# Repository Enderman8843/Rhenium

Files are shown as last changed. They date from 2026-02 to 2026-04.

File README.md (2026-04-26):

# Rhenium 
It is a Keyboard that is powered by RP2040 microprocessor that uses a USB-C, this keyboard is using akko v3 pro black switches also this has a layout of a slight variation of ANSI-104 

### Demo : https://drive.google.com/file/d/1mEruNO0NkJvDSLDQcf2VO9Js_aKwS2UY/view?usp=sharing
### Demo : https://drive.google.com/file/d/1Fq-R3P4Wu6ONQhNlfD0M-4PFkLKanZj8/view
# Photos


# KMK FIRMWARE 
*ALWAYS USE THIS
1. Install CircuitPY
2. Copy these files: -https://github.com/Enderman8843/Rhenium/tree/f9bf0482101a7b040eca7897d7e98482e09b73b1/firmware/KMK%20FIRMWARE

# QMK FIRMWARE 
*Bit Glitchy 
1. Put this UF2 in rpi
https://github.com/Enderman8843/Rhenium/tree/909fbee6c6720d5a931a36db898d5d94f6ce02c9/firmware/UF2FILES/QMK

## Why Rhenium?
Personally I had never used a mechanical keyboard in my life and only relied on cheap membrane keyboard or use my laptop's keyboard , But when I heard about Blueprint I decided to change it all at once and build myself a Mechanical keyboard , And also decided that I need to have everything custom nothing extrenal thus I embeded the microprocessor into the pcb making it better!

Rhenium was named after the inspiration taken from the chromium browser!

## How To Use ?
To use this computer appartus I would suggest using your biological input device so called digits i.e. fingers ,Begin by selecting finger of your choice then elevate your finger about 0.3-0.4 cm above the desired key then place it in on that particular key then gently apply 0.30N of magnitude of force this would lead your visual display unit to render the desired character represented by the key , Simple as that

Before that make sure the assemeble the keyboard and connect it via the usb-c , and to flash the firmware use the bootsel btn and read the above for both KMK and QMK
## Case Render

| Top & Side View | Rear view |
|---|---|
|  |  |

| Full Assembly View |
|-------------------|
|  |

---

## PCB Layout and Render

| PCB  | Schematics /Wiring |
|---|---|
|  | |
| 3D view |
|-------------------|
|||

## JLCPCB ORDER 


## Shipment Option 


See I did not find gdsr option so I chose UPS world wide express shipment

## BOM
| Item | Description | Quantity | Unit Price ($) | Total Price ($) | URL |
|---|---|---|---|---|-----|
| PCB | JLCPCB | 1 | 113.66 | 113.66 | https://jlcpcb.com |
| Pinecil V2 | Solder Iron | 1 | OWNED | 0.00 | OWNED |
| Diodes | Diodes | 75 | 0.01 | 1 | Owned |
| Case | Print Legion Shipment | 1 | 6.00 | 6.00 | https://hackclub.com |
| Akko Switches | Switch Set (45) | 2 | 14.00 | 28.00 | https://stackskb.com/store/akko-v3-cream-black-pro-switch-pack-of-45/ |
| Keycaps | MDA Profile Keycaps | 1 | 16.69 | 16.69 | https://stackskb.com/store/stackspbt-lavender-mda-profile-keycaps-131-key/ |
| OLED Display | 0.91" OLED Display | 1 | 2.23 | 2.23 | https://robu.in/product/blue-oled-display-module/ |
| Vertical Rotary Encoder | Rotary Encoder | 1 | 2.00 | 2.00 | https://www.amazon.in/dp/B0888RWNM1 |
| Rotary Cap | Knob Cap | 1 | 0.40 | 0.40 | https://robu.in/product/potentiometer-knob-rotary-switch-cap-black-color-pack-of-5-pcs/ |
| M2 Screw + Hex + Washer | Misc Hardware | 6 | 0.80 | 0.80 | https://onlyscrews.in/products/m2-nut-ss-304 |
| Soldering Essentials | Solder+Flux+TipCleaner | 1 | 4.54 | 4.54 | https://robocraze.com/products/7cmx5-5cm-soldering-cleaning-sponge-for-soldering-irons-work-stands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 , https://robu.in/product/solder-wire-0-8mm50g/ , https://robu.in/product/noel-flux-soldering-paste-10g/ |
| **TOTAL** |  |  |  | **175 $** |  |

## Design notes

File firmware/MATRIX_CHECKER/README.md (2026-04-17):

This files helped me quite a lot to find the wrong diodes in my keyboard

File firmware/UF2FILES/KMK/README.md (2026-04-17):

It is the default circuitpy uf2 , You have to put the files from KMK firware in circuitpy disk then it will work

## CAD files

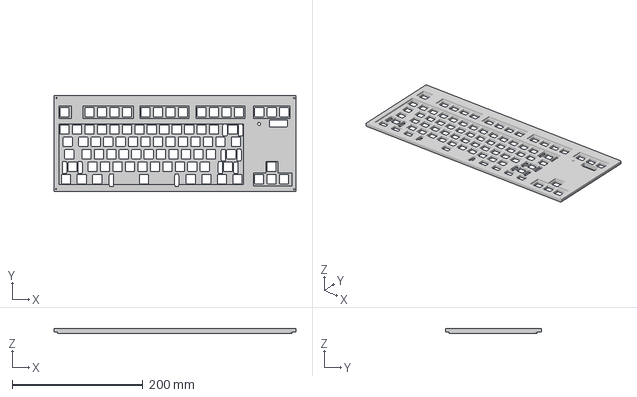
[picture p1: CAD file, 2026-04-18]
CAD/3d_Printable Files/LEFT_KEEBPLATE.3mf
370.0 x 146.1 x 7.20 mm

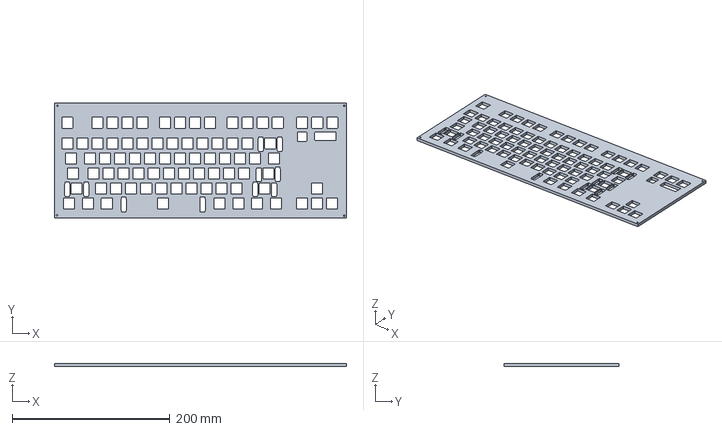
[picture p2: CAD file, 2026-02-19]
CAD/Keyboard_Plate.step
370.0 x 146.1 x 4.00 mm

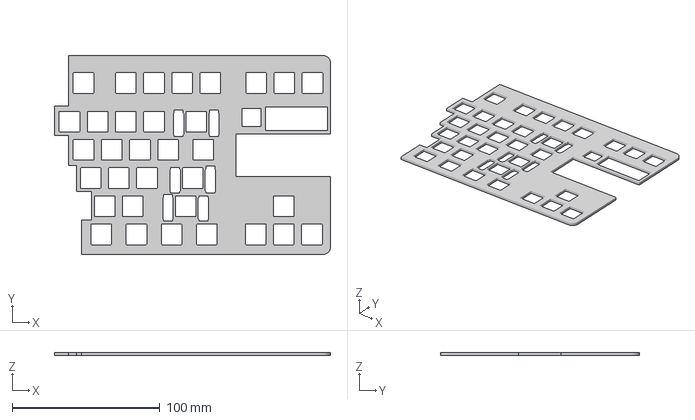
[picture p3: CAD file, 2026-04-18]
CAD/3d_Printable Files/RIGHT_KEEBPLATE.3mf
186.6 x 134.4 x 2.20 mm

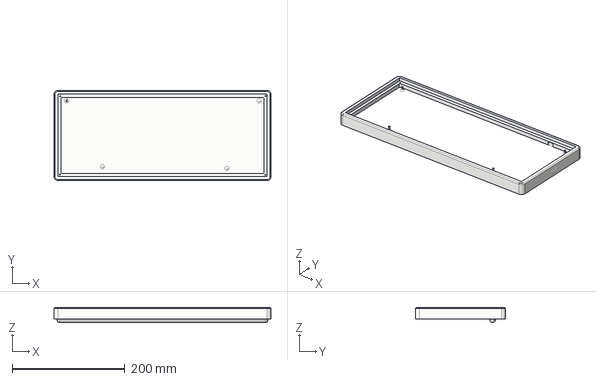
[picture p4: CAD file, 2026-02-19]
CAD/Keyboard_Body.step
384.6 x 159.5 x 26.9 mm

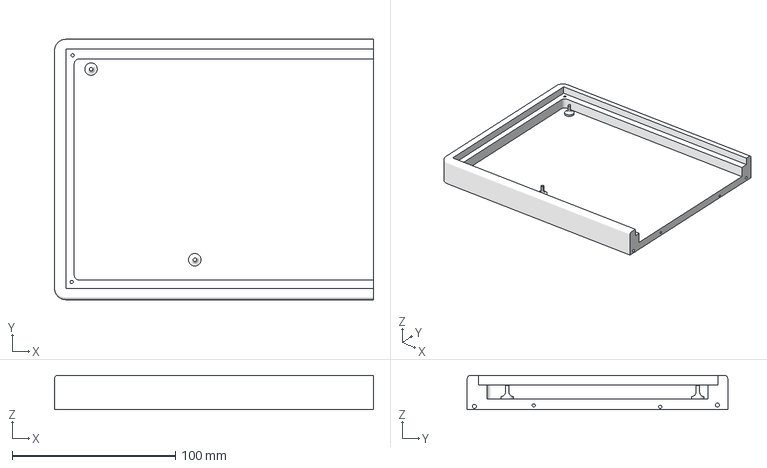
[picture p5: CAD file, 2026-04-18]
CAD/3d_Printable Files/BODY_RIGHT.3mf
195.3 x 159.5 x 21.0 mm

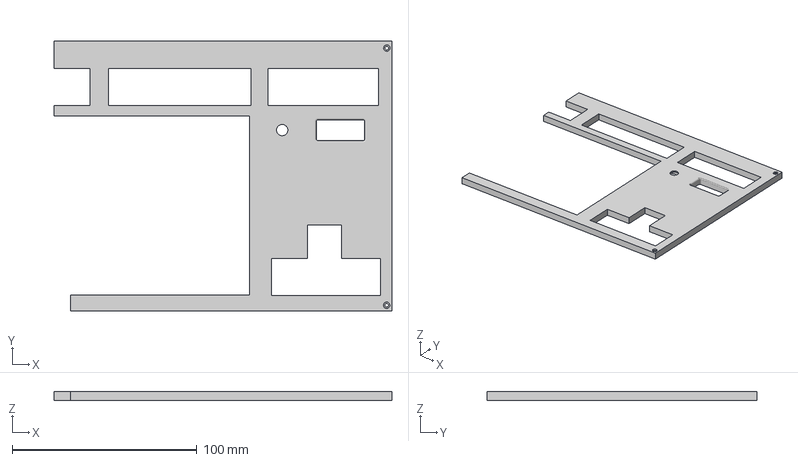
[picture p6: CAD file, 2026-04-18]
CAD/3d_Printable Files/TOP_LEFT.3mf
183.2 x 146.1 x 5.00 mm

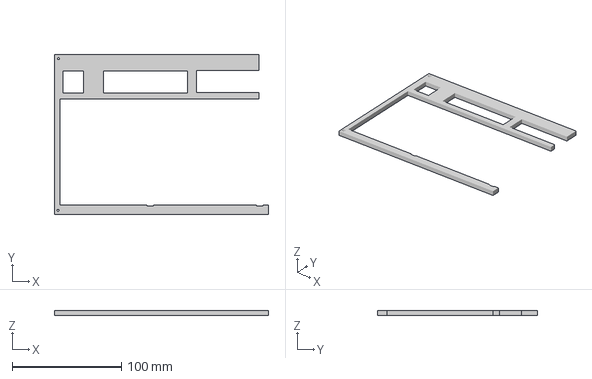
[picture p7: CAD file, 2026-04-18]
CAD/3d_Printable Files/TOP_RIGHT.3mf
195.7 x 146.1 x 4.90 mm

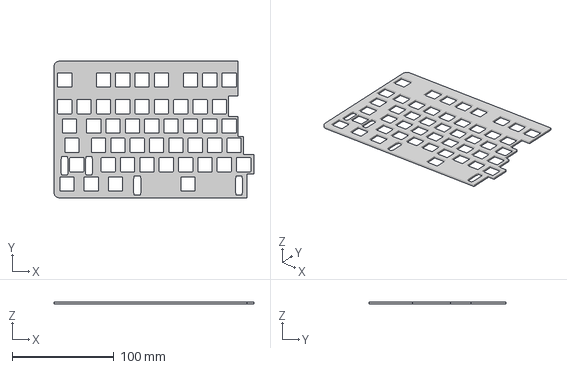
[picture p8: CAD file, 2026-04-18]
CAD/3d_Printable Files/RIGHTSIDE.3mf
196.9 x 134.4 x 2.20 mm

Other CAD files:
CAD/3d_Printable Files/LEFTSIDE.3mf

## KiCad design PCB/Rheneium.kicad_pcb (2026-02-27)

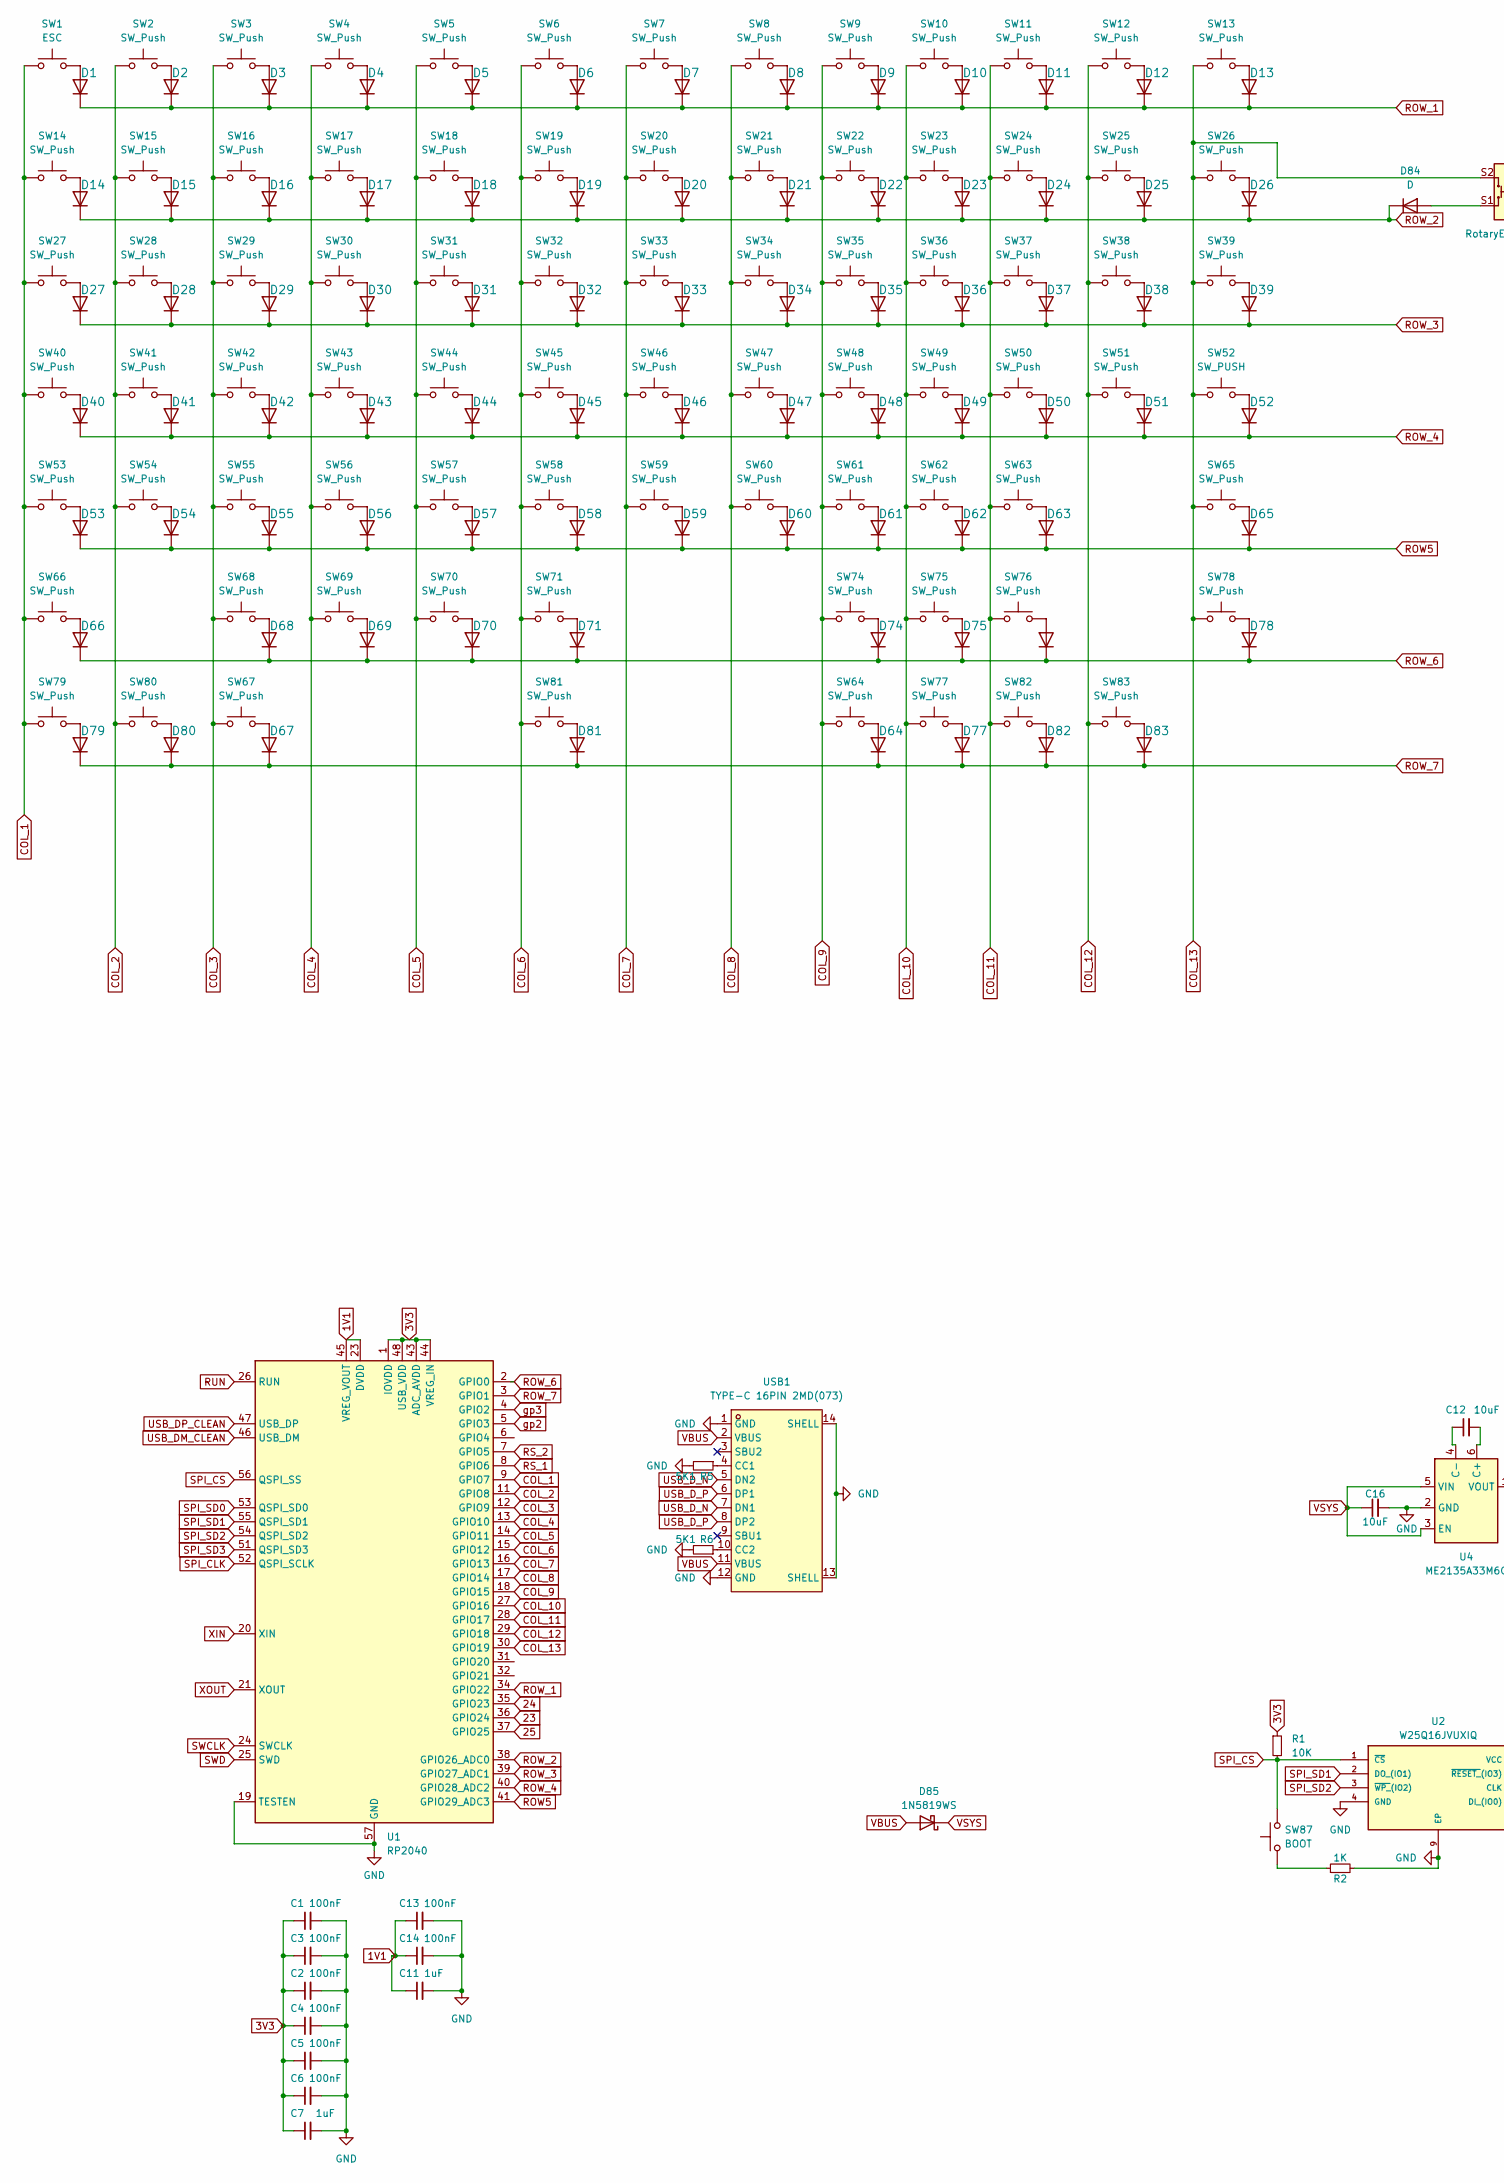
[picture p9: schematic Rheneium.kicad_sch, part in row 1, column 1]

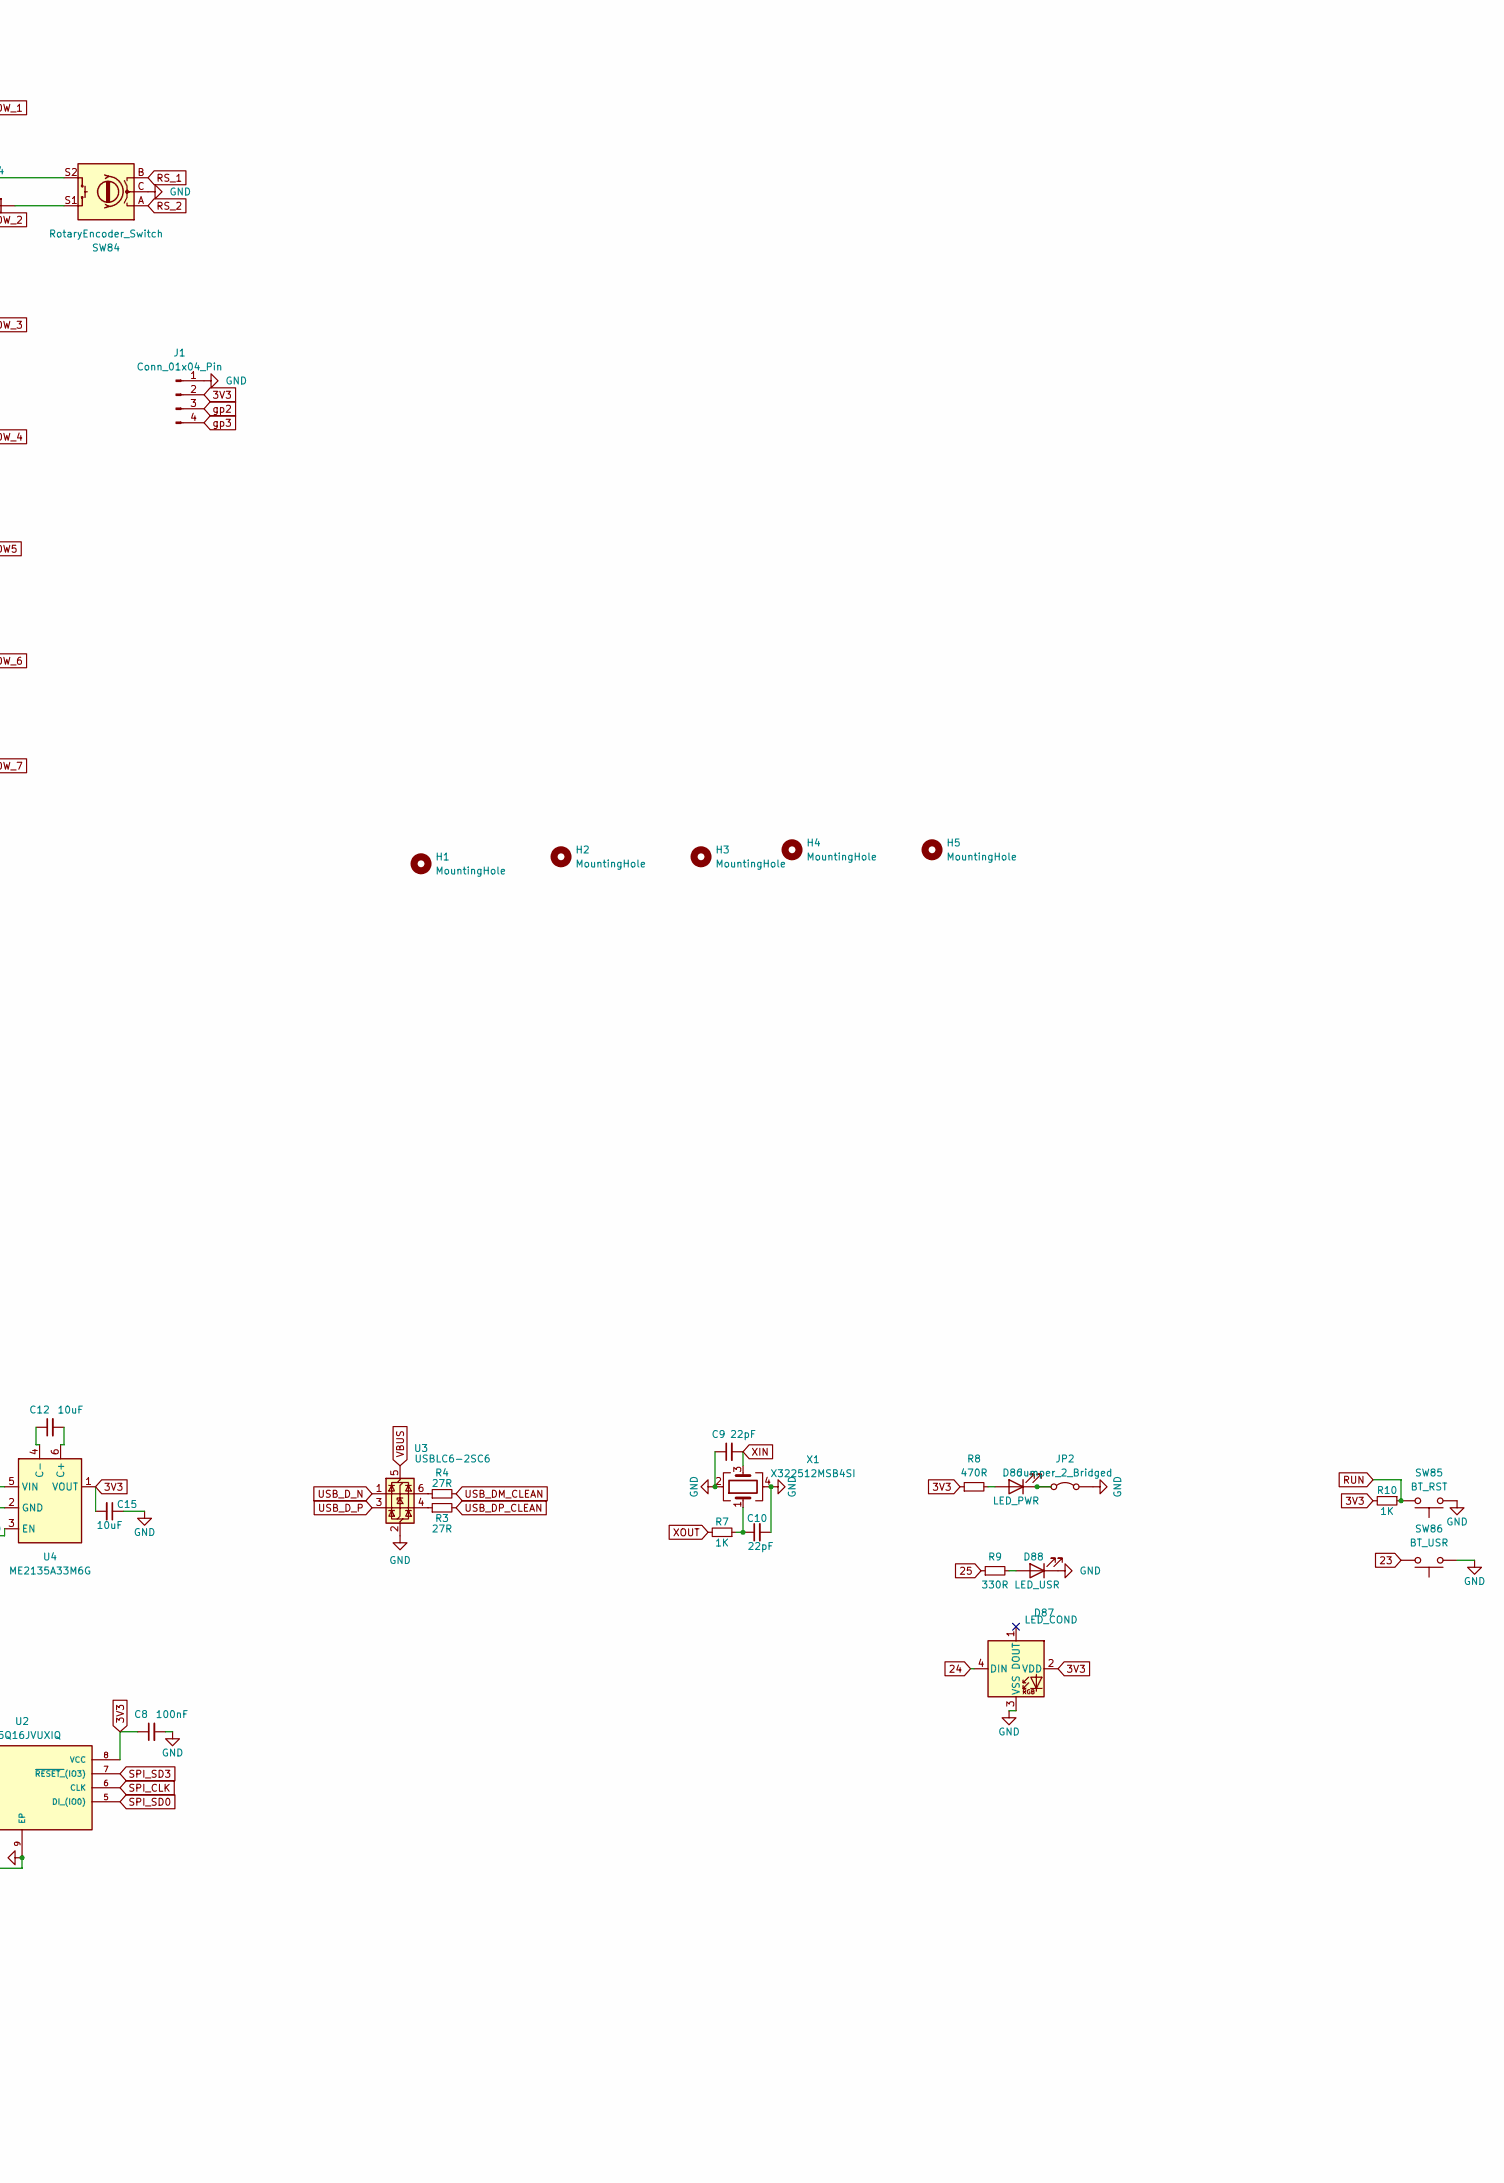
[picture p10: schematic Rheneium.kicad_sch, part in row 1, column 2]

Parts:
C1, C2, C3, C4, C5, C6, C8, C13, C14: 100nF; C_0402_1005Metric
C7, C11: 1uF; C_0402_1005Metric
C9, C10: 22pF; C_0402_1005Metric
C12: 10uF; C_0805_2012Metric
C15, C16: 10uF; C_0402_1005Metric
D1, D2, D3, D4, D5, D6, D7, D8, D9, D10, D11, D12, D13, D14, D15, D16, D17, D18, D19, D20, D21, D22, D23, D24, D25, D26, D27, D28, D29, D30, D31, D32, D33, D34, D35, D36, D37, D38, D39, D40, D41, D42, D43, D44, D45, D46, D47, D48, D49, D50, D51, D52, D53, D54, D55, D56, D57, D58, D59, D60, D61, D62, D63, D64, D65, D66, D67, D68, D69, D70, D71, D74, D75, D76, D77, D78, D79, D80, D81, D82, D83, D84: D; D_0805_2012Metric_Pad1.15x1.40mm_HandSolder
D85: 1N5819WS; D_SOD-323
D86: LED_PWR; LED_0603_1608Metric
D87: LED_COND; LED_SK6812MINI_PLCC4_3.5x3.5mm_P1.75mm
D88: LED_USR; LED_0603_1608Metric
H1, H2, H3, H4, H5: MountingHole; MountingHole_2.2mm_M2
J1: Conn_01x04_Pin; SSD1306-0.91-OLED-4pin-128x32
JP2: Jumper_2_Bridged; SolderJumper-2_P1.3mm_Bridged2Bar_RoundedPad1.0x1.5mm
R1: 10K; R_0402_1005Metric
R2, R7, R10: 1K; R_0402_1005Metric
R3, R4: 27R; R_0402_1005Metric
R5, R6: 5K1; R_0402_1005Metric
R8: 470R; R_0402_1005Metric
R9: 330R; R_0402_1005Metric
SW1: ESC; SW_Cherry_MX_1.00u_PCB
SW2, SW3, SW4, SW5, SW6, SW7, SW8, SW9, SW10, SW11, SW12, SW13, SW14, SW15, SW16, SW17, SW18, SW19, SW20, SW21, SW22, SW23, SW24, SW25, SW28, SW29, SW30, SW31, SW32, SW33, SW34, SW35, SW36, SW37, SW38, SW41, SW42, SW43, SW44, SW45, SW46, SW47, SW48, SW49, SW50, SW51, SW54, SW55, SW56, SW57, SW58, SW59, SW60, SW61, SW62, SW63, SW66, SW68, SW69, SW70, SW71, SW74, SW75, SW76, SW78: SW_Push; SW_Cherry_MX_1.00u_PCB
SW26: SW_Push; SW_Cherry_MX_2.00u_PCB
SW27, SW39: SW_Push; SW_Cherry_MX_1.50u_PCB
SW40: SW_Push; SW_Cherry_MX_1.75u_PCB
SW52: SW_PUSH; SW_Cherry_MX_2.25u_PCB
SW53: SW_Push; SW_Cherry_MX_2.25u_PCB
SW64, SW67, SW77, SW79, SW80, SW82, SW83: SW_Push; SW_Cherry_MX_1.25u_PCB
SW65: SW_Push; SW_Cherry_MX_2.75u_PCB
SW81: SW_Push; SW_Cherry_MX_6.25u_PCB
SW84: RotaryEncoder_Switch; RotaryEncoder_Alps_EC11E-Switch_Vertical_H20mm
SW85: BT_RST; SW_Push_1P1T_NO_CK_KMR2
SW86: BT_USR; SW_Push_1P1T_NO_CK_KMR2
SW87: BOOT; SW_Push_1P1T_NO_CK_KMR2
U1: RP2040; QFN-56-1EP_7x7mm_P0.4mm_EP3.2x3.2mm
U2: W25Q16JVUXIQ; Winbond_USON-8-1EP_3x2mm_P0.5mm_EP0.2x1.6mm; MANUFACTURER_PART_NUMBER W25Q16JVUXIQ; LCSC C2843335
U3: USBLC6-2SC6; SOT-23-6
U4: ME2135A33M6G; SOT-23-6; LCSC C610271
USB1: TYPE-C 16PIN 2MD(073); USB-C-SMD_TYPE-C-6PIN-2MD-073; LCSC Part C2765186
X1: X322512MSB4SI; Crystal_SMD_3225-4Pin_3.2x2.5mm; LCSC C9002

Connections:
1V1: C11.1, C13.1, C14.1, U1.23 (DVDD), U1.45 (VREG_VOUT), U1.50 (DVDD)
3V3: C1.1, C2.1, C3.1, C4.1, C5.1, C6.1, C7.1, C8.1, C15.2, D87.2 (VDD), J1.2, R1.1, R8.1, R10.2, U1.1 (IOVDD), U1.10 (IOVDD), U1.22 (IOVDD), U1.33 (IOVDD), U1.42 (IOVDD), U1.43 (ADC_AVDD), U1.44 (VREG_IN), U1.48 (USB_VDD), U1.49 (IOVDD), U2.8 (VCC), U4.1 (VOUT)
23: SW86.2, U1.36 (GPIO24)
24: D87.4 (DIN), U1.35 (GPIO23)
25: R9.1, U1.37 (GPIO25)
COL_1: SW1.1, SW14.1, SW27.1, SW40.1, SW53.1, SW66.1, SW79.1, U1.9 (GPIO7)
COL_2: SW2.1, SW15.1, SW28.1, SW41.1, SW54.1, SW80.1, U1.11 (GPIO8)
COL_3: SW3.1, SW16.1, SW29.1, SW42.1, SW55.1, SW67.1, SW68.1, U1.12 (GPIO9)
COL_4: SW4.1, SW17.1, SW30.1, SW43.1, SW56.1, SW69.1, U1.13 (GPIO10)
COL_5: SW5.1, SW18.1, SW31.1, SW44.1, SW57.1, SW70.1, U1.14 (GPIO11)
COL_6: SW6.1, SW19.1, SW32.1, SW45.1, SW58.1, SW71.1, SW81.1, U1.15 (GPIO12)
COL_7: SW7.1, SW20.1, SW33.1, SW46.1, SW59.1, U1.16 (GPIO13)
COL_8: SW8.1, SW21.1, SW34.1, SW47.1, SW60.1, U1.17 (GPIO14)
COL_9: SW9.1, SW22.1, SW35.1, SW48.1, SW61.1, SW64.1, SW74.1, U1.18 (GPIO15)
COL_10: SW10.1, SW23.1, SW36.1, SW49.1, SW62.1, SW75.1, SW77.1, U1.27 (GPIO16)
COL_11: SW11.1, SW24.1, SW37.1, SW50.1, SW63.1, SW76.1, SW82.1, U1.28 (GPIO17)
COL_12: SW12.1, SW25.1, SW38.1, SW51.1, SW83.1, U1.29 (GPIO18)
COL_13: SW13.1, SW26.1, SW39.1, SW52.1, SW65.1, SW78.1, SW84.S2, U1.30 (GPIO19)
GND: C1.2, C2.2, C3.2, C4.2, C5.2, C6.2, C7.2, C8.2, C9.1, C10.2, C11.2, C13.2, C14.2, C15.1, C16.2, D87.3 (VSS), D88.1 (K), J1.1, JP2.2 (B), R2.2, R5.2, R6.2, SW84.C, SW85.1, SW86.1, U1.19 (TESTEN), U1.57 (GND), U2.4 (GND), U2.9 (EP), U3.2 (GND), U4.2 (GND), USB1.1 (GND), USB1.12 (GND), USB1.13 (SHELL), USB1.14 (SHELL), X1.2, X1.4
unnamed: C10.1, R7.1, X1.1
unnamed: D1.2 (A), SW1.2
unnamed: D2.2 (A), SW2.2
unnamed: D3.2 (A), SW3.2
unnamed: D4.2 (A), SW4.2
unnamed: D5.2 (A), SW5.2
unnamed: D6.2 (A), SW6.2
unnamed: D7.2 (A), SW7.2
unnamed: D8.2 (A), SW8.2
unnamed: D9.2 (A), SW9.2
unnamed: D10.2 (A), SW10.2
unnamed: D11.2 (A), SW11.2
unnamed: D12.2 (A), SW12.2
unnamed: D13.2 (A), SW13.2
unnamed: D14.2 (A), SW14.2
unnamed: D15.2 (A), SW15.2
unnamed: D16.2 (A), SW16.2
unnamed: D17.2 (A), SW17.2
unnamed: D18.2 (A), SW18.2
unnamed: D19.2 (A), SW19.2
unnamed: D20.2 (A), SW20.2
unnamed: D21.2 (A), SW21.2
unnamed: D22.2 (A), SW22.2
unnamed: D23.2 (A), SW23.2
unnamed: D24.2 (A), SW24.2
unnamed: D25.2 (A), SW25.2
unnamed: D26.2 (A), SW26.2
unnamed: D27.2 (A), SW27.2
unnamed: D28.2 (A), SW28.2
unnamed: D29.2 (A), SW29.2
unnamed: D30.2 (A), SW30.2
unnamed: D31.2 (A), SW31.2
unnamed: D32.2 (A), SW32.2
unnamed: D33.2 (A), SW33.2
unnamed: D34.2 (A), SW34.2
unnamed: D35.2 (A), SW35.2
unnamed: D36.2 (A), SW36.2
unnamed: D37.2 (A), SW37.2
unnamed: D38.2 (A), SW38.2
unnamed: D39.2 (A), SW39.2
unnamed: D40.2 (A), SW40.2
unnamed: D41.2 (A), SW41.2
unnamed: D42.2 (A), SW42.2
unnamed: D43.2 (A), SW43.2
unnamed: D44.2 (A), SW44.2
unnamed: D45.2 (A), SW45.2
unnamed: D46.2 (A), SW46.2
unnamed: D47.2 (A), SW47.2
unnamed: D48.2 (A), SW48.2
unnamed: D49.2 (A), SW49.2
unnamed: D50.2 (A), SW50.2
unnamed: D51.2 (A), SW51.2
unnamed: D52.2 (A), SW52.2
unnamed: D53.2 (A), SW53.2
unnamed: D54.2 (A), SW54.2
unnamed: D55.2 (A), SW55.2
unnamed: D56.2 (A), SW56.2
unnamed: D57.2 (A), SW57.2
unnamed: D58.2 (A), SW58.2
unnamed: D59.2 (A), SW59.2
unnamed: D60.2 (A), SW60.2
unnamed: D61.2 (A), SW61.2
unnamed: D62.2 (A), SW62.2
unnamed: D63.2 (A), SW63.2
unnamed: D64.2 (A), SW64.2
unnamed: D65.2 (A), SW65.2
unnamed: D66.2 (A), SW66.2
unnamed: D67.2 (A), SW67.2
unnamed: D68.2 (A), SW68.2
unnamed: D69.2 (A), SW69.2
unnamed: D70.2 (A), SW70.2
unnamed: D71.2 (A), SW71.2
unnamed: D74.2 (A), SW74.2
unnamed: D75.2 (A), SW75.2
unnamed: D76.2 (A), SW76.2
unnamed: D77.2 (A), SW77.2
unnamed: D78.2 (A), SW78.2
unnamed: D79.2 (A), SW79.2
unnamed: D80.2 (A), SW80.2
unnamed: D81.2 (A), SW81.2
unnamed: D82.2 (A), SW82.2
unnamed: D83.2 (A), SW83.2
unnamed: D84.2 (A), SW84.S1
unnamed: D86.2 (A), R8.2
unnamed: D86.1 (K), JP2.1 (A)
unnamed: D88.2 (A), R9.2
unnamed: R2.1, SW87.1
unnamed: R3.1, U3.4 (I/O2)
unnamed: R4.1, U3.6 (I/O1)
unnamed: C12.2, U4.6 (C+)
unnamed: C12.1, U4.4 (C-)
unnamed: R5.1, USB1.4 (CC1)
unnamed: R6.1, USB1.10 (CC2)
ROW5: D53.1 (K), D54.1 (K), D55.1 (K), D56.1 (K), D57.1 (K), D58.1 (K), D59.1 (K), D60.1 (K), D61.1 (K), D62.1 (K), D63.1 (K), D65.1 (K), U1.41 (GPIO29_ADC3)
ROW_1: D1.1 (K), D2.1 (K), D3.1 (K), D4.1 (K), D5.1 (K), D6.1 (K), D7.1 (K), D8.1 (K), D9.1 (K), D10.1 (K), D11.1 (K), D12.1 (K), D13.1 (K), U1.34 (GPIO22)
ROW_2: D14.1 (K), D15.1 (K), D16.1 (K), D17.1 (K), D18.1 (K), D19.1 (K), D20.1 (K), D21.1 (K), D22.1 (K), D23.1 (K), D24.1 (K), D25.1 (K), D26.1 (K), D84.1 (K), U1.38 (GPIO26_ADC0)
ROW_3: D27.1 (K), D28.1 (K), D29.1 (K), D30.1 (K), D31.1 (K), D32.1 (K), D33.1 (K), D34.1 (K), D35.1 (K), D36.1 (K), D37.1 (K), D38.1 (K), D39.1 (K), U1.39 (GPIO27_ADC1)
ROW_4: D40.1 (K), D41.1 (K), D42.1 (K), D43.1 (K), D44.1 (K), D45.1 (K), D46.1 (K), D47.1 (K), D48.1 (K), D49.1 (K), D50.1 (K), D51.1 (K), D52.1 (K), U1.40 (GPIO28_ADC2)
ROW_6: D66.1 (K), D68.1 (K), D69.1 (K), D70.1 (K), D71.1 (K), D74.1 (K), D75.1 (K), D76.1 (K), D78.1 (K), U1.2 (GPIO0)
ROW_7: D64.1 (K), D67.1 (K), D77.1 (K), D79.1 (K), D80.1 (K), D81.1 (K), D82.1 (K), D83.1 (K), U1.3 (GPIO1)
RS_1: SW84.B, U1.8 (GPIO6)
RS_2: SW84.A, U1.7 (GPIO5)
RUN: R10.1, SW85.2, U1.26 (RUN)
SPI_CLK: U1.52 (QSPI_SCLK), U2.6 (CLK)
SPI_CS: R1.2, SW87.2, U1.56 (QSPI_SS), U2.1 (~CS)
SPI_SD0: U1.53 (QSPI_SD0), U2.5 (DI_(IO0))
SPI_SD1: U1.55 (QSPI_SD1), U2.2 (DO_(IO1))
SPI_SD2: U1.54 (QSPI_SD2), U2.3 (~WP_(IO2))
SPI_SD3: U1.51 (QSPI_SD3), U2.7 (~RESET_(IO3))
SWCLK: U1.24 (SWCLK)
SWD: U1.25 (SWD)
USB_DM_CLEAN: R4.2, U1.46 (USB_DM)
USB_DP_CLEAN: R3.2, U1.47 (USB_DP)
USB_D_N: U3.1 (I/O1), USB1.5 (DN2), USB1.7 (DN1)
USB_D_P: U3.3 (I/O2), USB1.6 (DP1), USB1.8 (DP2)
VBUS: D85.2 (A), U3.5 (VBUS), USB1.2 (VBUS), USB1.11 (VBUS)
VSYS: C16.1, D85.1 (K), U4.3 (EN), U4.5 (VIN)
XIN: C9.2, U1.20 (XIN), X1.3
XOUT: R7.2, U1.21 (XOUT)
gp2: J1.3, U1.5 (GPIO3)
gp3: J1.4, U1.4 (GPIO2)

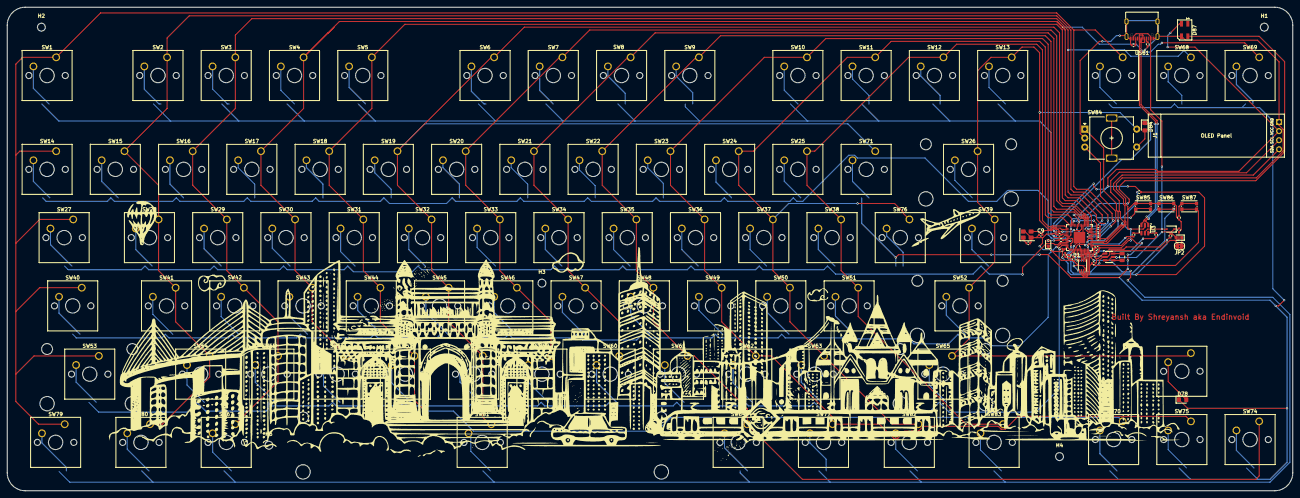
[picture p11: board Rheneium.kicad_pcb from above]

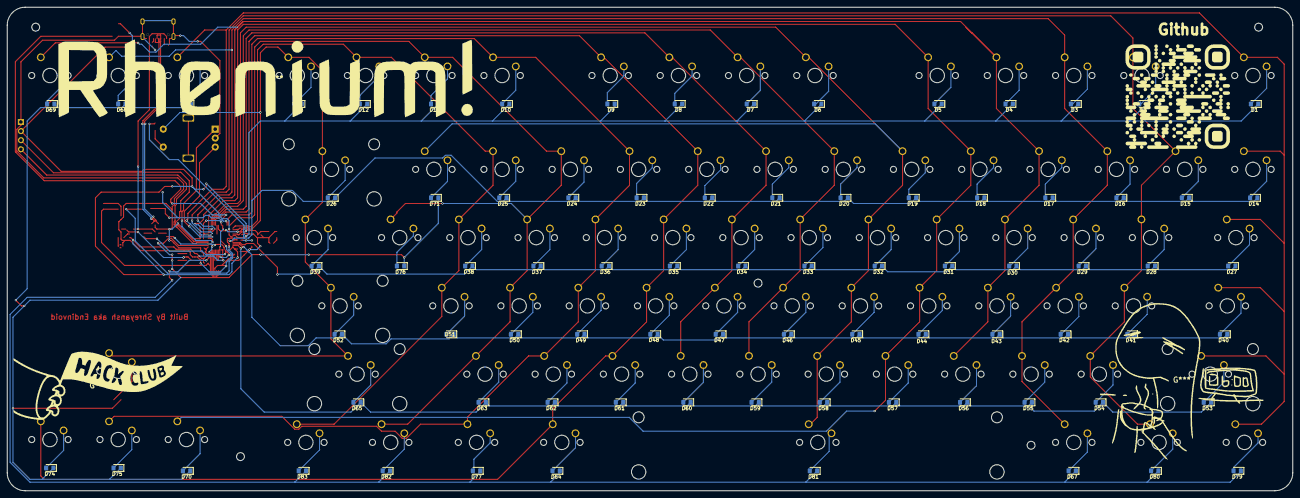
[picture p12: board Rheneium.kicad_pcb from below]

Board: 2 copper layers, 358.8 x 134.9 mm, 209 parts (80 on the bottom side), 137 nets.

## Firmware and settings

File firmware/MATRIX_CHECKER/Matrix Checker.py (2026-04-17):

from kmk.kmk_keyboard import KMKKeyboard
from kmk.keys import KC
from kmk.scanners import DiodeOrientation
import board
import time
import busio
import adafruit_ssd1306

keyboard = KMKKeyboard()

# ---------------- MATRIX ----------------
keyboard.row_pins = (
    board.GP16, board.GP17, board.GP18,
    board.GP19, board.GP20, board.GP21, board.GP22
)

keyboard.col_pins = (
    board.GP2, board.GP3, board.GP4, board.GP5,
    board.GP6, board.GP7, board.GP8,
    board.GP9, board.GP10, board.GP11,
    board.GP12, board.GP13, board.GP14
)

# ⚠️ If keys don't work, switch this
keyboard.diode_orientation = DiodeOrientation.COL2ROW
# keyboard.diode_orientation = DiodeOrientation.ROW2COL


# ---------------- OLED ----------------
i2c = busio.I2C(scl=board.GP27, sda=board.GP26)
oled = adafruit_ssd1306.SSD1306_I2C(128, 32, i2c, addr=0x3C)

# Fix orientation (very common issue)
oled.rotate(2)


# ---------------- BOOT ----------------
def boot_logo():
    oled.fill(0)
    oled.text("RHENIUM", 30, 8, 1)
    oled.text("READY", 40, 18, 1)
    oled.show()
    time.sleep(1.2)

boot_logo()


# ---------------- STATS ----------------
start_time = time.monotonic()
keypress_count = 0
last_key = ""
last_oled_update = 0


def get_wpm():
    elapsed = time.monotonic() - start_time
    if elapsed == 0:
        return 0
    return int((keypress_count / 5) / (elapsed / 60))


# ---------------- KEY HANDLING (FIXED) ----------------
keyboard._orig_process_key = keyboard.process_key

def process_key(key, is_pressed, int_coord):
    global keypress_count, last_key

    if is_pressed:
        keypress_count += 1
        last_key = str(key).replace("KC.", "")

    # IMPORTANT: pass back to KMK
    return keyboard._orig_process_key(key, is_pressed, int_coord)

keyboard.process_key = process_key


# ---------------- OLED RENDER (FAST) ----------------
def render_oled():
    oled.fill(0)

    # Key (top row)
    oled.text("K:" + last_key[:6], 0, 0, 1)

    # WPM (bottom row)
    oled.text("WPM:" + str(get_wpm()), 0, 16, 1)

    oled.show()


# ---------------- THROTTLED UPDATE ----------------
def after_matrix_scan(*args):
    global last_oled_update

    now = time.monotonic()

    # Update at ~5 FPS (no lag)
    if now - last_oled_update > 0.2:
        last_oled_update = now
        render_oled()

keyboard.after_matrix_scan = after_matrix_scan


# ---------------- KEYMAP ----------------
keyboard.keymap = [[
    KC.ESC, KC.F1, KC.F2, KC.F3, KC.F4, KC.F5, KC.F6, KC.F7, KC.F8, KC.F9, KC.F10, KC.F11, KC.F12,
    KC.GRV, KC.N1, KC.N2, KC.N3, KC.N4, KC.N5, KC.N6, KC.N7, KC.N8, KC.N9, KC.N0, KC.MINS, KC.BSPC,
    KC.TAB, KC.Q, KC.W, KC.E, KC.R, KC.T, KC.Y, KC.U, KC.I, KC.O, KC.P, KC.LBRC, KC.BSLS,
    KC.CAPS, KC.A, KC.S, KC.D, KC.F, KC.G, KC.H, KC.J, KC.K, KC.L, KC.SCLN, KC.QUOT, KC.ENTER,
    KC.LSHIFT, KC.Z, KC.X, KC.C, KC.V, KC.B, KC.N, KC.M, KC.COMM, KC.DOT, KC.SLSH, KC.NO, KC.RSHIFT,
    KC.PSCR, KC.NO, KC.NO, KC.PAUSE, KC.LEFT, KC.EQL, KC.NO, KC.NO, KC.RIGHT, KC.DOWN, KC.RBRC, KC.NO, KC.UP,
    KC.LCTRL, KC.LGUI, KC.LALT, KC.NO, KC.NO, KC.SPACE, KC.NO, KC.NO, KC.RALT, KC.NO, KC.APP, KC.RCTRL, KC.NO
]]


# ---------------- START ----------------
if __name__ == '__main__':
    keyboard.go()

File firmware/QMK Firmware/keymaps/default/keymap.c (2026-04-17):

#include QMK_KEYBOARD_H

#define ENCODER_MAP_ENABLE

bool encoder_mode = false;
uint8_t volume_level = 50;
uint8_t brightness_level = 50;

const uint16_t PROGMEM keymaps[][MATRIX_ROWS][MATRIX_COLS] = {
[0] = LAYOUT(
KC_ESC, KC_F1, KC_F2, KC_F3, KC_F4, KC_F5, KC_F6, KC_F7, KC_F8, KC_F9, KC_F10, KC_F11, KC_F12,
KC_GRV, KC_1, KC_2, KC_3, KC_4, KC_5, KC_6, KC_7, KC_8, KC_9, KC_0, KC_MINS, KC_BSPC,
KC_TAB, KC_Q, KC_W, KC_E, KC_R, KC_T, KC_Y, KC_U, KC_I, KC_O, KC_P, KC_LBRC, KC_BSLS,
KC_CAPS, KC_A, KC_S, KC_D, KC_F, KC_G, KC_H, KC_J, KC_K, KC_L, KC_SCLN, KC_QUOT, KC_ENT,
KC_LSFT, KC_Z, KC_X, KC_C, KC_V, KC_B, KC_N, KC_M, KC_COMM, KC_DOT, KC_SLSH, KC_NO, KC_RSFT,
KC_PSCR, KC_NO, KC_NO, KC_PAUS, KC_LEFT, KC_EQL, KC_NO, KC_NO, KC_RGHT, KC_DOWN, KC_RBRC, KC_NO, KC_UP,
KC_LCTL, KC_LGUI, KC_LALT, KC_NO, KC_NO, KC_SPC, KC_NO, KC_NO, KC_RALT, KC_NO, KC_APP, KC_RCTL, KC_NO
)
};

// ---------- ENCODER ----------
bool encoder_update_user(uint8_t index, bool clockwise) {
    if (!encoder_mode) {
        tap_code(clockwise ? KC_VOLU : KC_VOLD);
        volume_level = clockwise ? volume_level + 2 : volume_level - 2;
    } else {
        tap_code(clockwise ? KC_BRIU : KC_BRID);
        brightness_level = clockwise ? brightness_level + 2 : brightness_level - 2;
    }
    return false;
}

// ---------- BUTTON ----------
bool encoder_button_user(uint8_t index, bool pressed) {
    if (pressed) {
        encoder_mode = !encoder_mode;
    }
    return true;
}

#ifdef OLED_ENABLE

void draw_bar(uint8_t level) {
    uint8_t bars = level / 10;
    for (int i = 0; i < 10; i++) {
        oled_write(i < bars ? "|" : ".", false);
    }
}

bool oled_task_user(void) {

    oled_set_cursor(0, 0);
    oled_write_ln("RHENIUM", false);

    oled_set_cursor(0, 1);
    oled_write_ln("------------", false);

    if (!encoder_mode) {
        oled_set_cursor(0, 2);
        oled_write_ln("VOLUME", false);

        oled_set_cursor(0, 3);
        draw_bar(volume_level);
    } else {
        oled_set_cursor(0, 2);
        oled_write_ln("BRIGHT", false);

        oled_set_cursor(0, 3);
        draw_bar(brightness_level);
    }

    return false;
}

#endif

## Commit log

2025-12-25 Created PCB folder
2025-12-26 Enhance Rhenium keyboard description in README
    Expanded the description of the Rhenium keyboard to include details about its microprocessor, connection type, switch compatibility, and layout.
2025-12-29 Added BOM
    [BOM_RHen.xlsx]
2025-12-31 Update PCB layout image in README
2026-01-02 did nothing
    [Rheneium.csv]
2026-01-06 Create pcbfiles
2026-01-06 Add BOM section to README
    Added Bill of Materials (BOM) section with item details.
2026-02-17 Refactor PCB layout images in README
2026-02-19 Update and rename Rhenium_Full.step to case/Rhenium_Full.step
    [Rhenium_Full.step]
2026-02-19 Create case
2026-02-27 Minor Changes
    [Rheneium.kicad_pcb]
2026-03-05 Update Schematics section in README
2026-03-05 Add diodes entry to the components table
2026-03-18 Update PCB description in BOM table
